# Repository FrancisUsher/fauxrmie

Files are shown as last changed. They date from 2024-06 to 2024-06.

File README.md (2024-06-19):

# fauxrmie

A derivative of the [2040rmie](https://github.com/shinkaimayano/2040rmie) drop-in PCB for the [40rmie](https://p3dstore.com/products/40rmie-invisibolt-acrylic-keyboard-case-and-pcb) family of keyboards using 40s modifiers.

The original [40s-2040rmie](https://github.com/shinkaimayano/40s-2040rmie) USB
port and rotary encoder position were slightly off. This probably didn't matter
for the acrylic or 3d printed cases, but for the 40rmie LX the tolerances seem
to have gotten a bit tighter, so I adjusted them to the correct position.

Additionally I simplified the layout options to only use the ones I am
interested in. It should be pretty straightforward to add additional e.g.
bottom-row layouts though.

## Status: Limited testing

I have tested this in my 40rmie LX using the no-blockers, no-encoders layout.

There should be no problems using the other layouts as I put quite a bit of
effort into checking the component positions matched the original PCB. However
_Order at your own risk!_

## Production

Dimensions: 309.5625mm x 112.0325mm

The files in `jlcpcb` should contain everything you need to need to order PCBA
from JLCPCB as of their January 2024 component selection.

The cost of production for 5 units was roughly $20 per unit with a 5 day turnaround:

- `$17` for PCB production (1 day)
- `$35.91` for components + PCB assembly (2 days)
- `$50` for DHL Express delivery (2 days)

## Renders

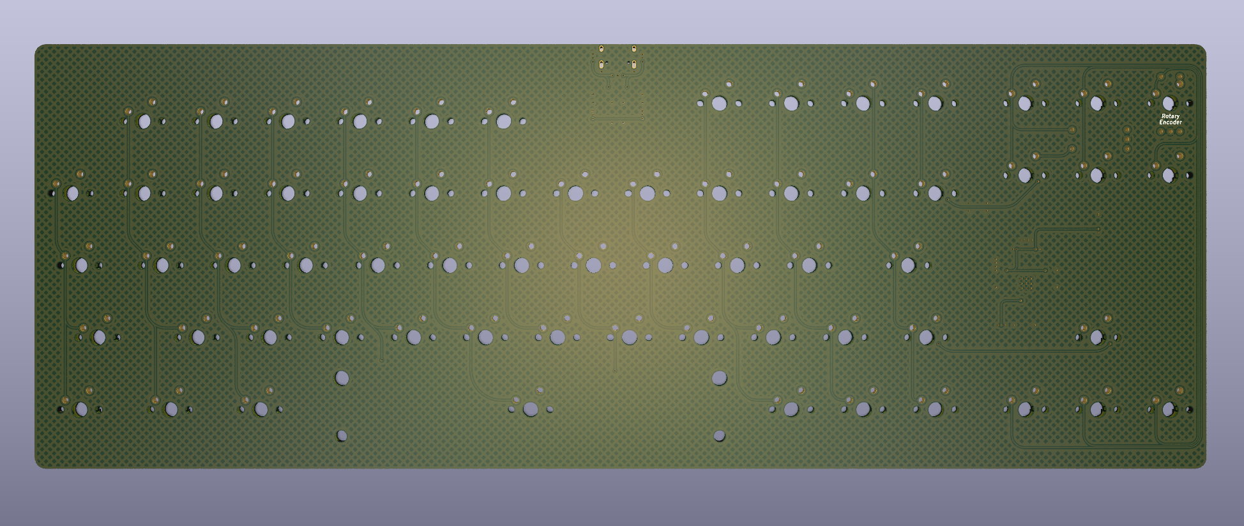
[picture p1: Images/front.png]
Front
  
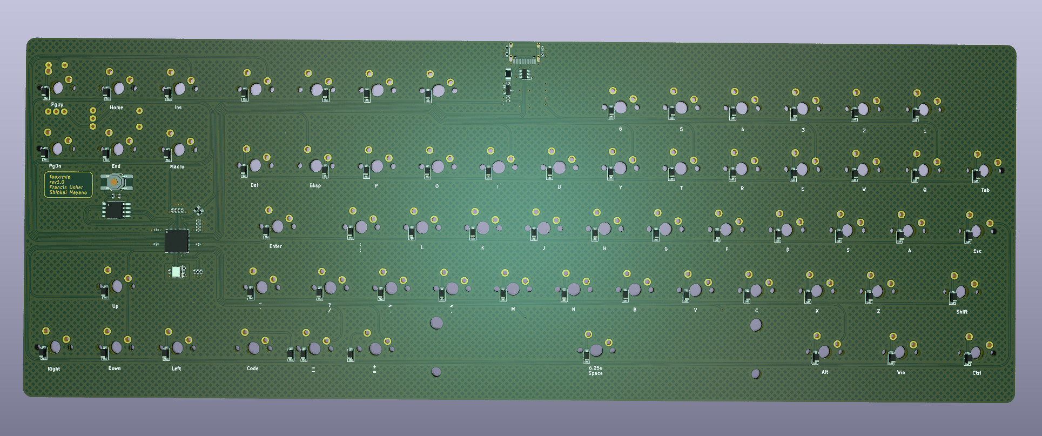
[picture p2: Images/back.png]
Back


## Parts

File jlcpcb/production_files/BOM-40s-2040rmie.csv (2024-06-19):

Comment | Designator | Footprint | LCSC
1k | R4,R8,R9 | R_0402_1005Metric | C11702
100nF | C12,C13,C14,C15,C16,C17,C18,C19,C20,C4,C8,C9 | C_0402_1005Metric | C1525
4.7nF | C3 | C_0402_1005Metric | C1538
22pF | C1,C2 | C_0402_1005Metric | C1555
HRO-M-12 | USB1 | USB_C_Receptacle_HRO_TYPE-C-31-M-12 | C165948
RP2040 | U1 | RP2040-QFN-56 | C2040
4.7uF | C10 | C_0402_1005Metric | C23733
27 | R2,R3 | R_0603_1608Metric | C25190
5.1k | R5,R6 | R_0402_1005Metric | C25905
1M | R7 | R_0402_1005Metric | C26083
Reset Button | Reset1 | SW_SPST_SKQG_WithStem | C318884
1uF | C11,C5,C6,C7 | C_0402_1005Metric | C52923
XC6206PxxxMR | U4 | SOT-23 | C5446
500mA | F1 | Fuse_1206_3216Metric | C70076
D_Small | D10,D11,D12,D13,D14,D15,D16,D17,D18,D19,D2,D20,D21,D22,D23,D24,D25,D26,D27,D28,D29,D3,D30,D31,D32,D33,D34,D35,D36,D37,D38,D39,D4,D40,D41,D42,D43,D44,D45,D46,D47,D48,D49,D5,D50,D51,D52,D53,D54,D55,D56,D57,D58,D59,D6,D63,D64,D65,D66,D67,D68,D7,D8,D9 | D_SOD-123 | C81598
SRV05-4 | U2 | SOT-23-6-routable | C85364
12MHz | Y1 | Crystal_SMD_3225-4Pin_3.2x2.5mm | C9002
W25Q128JVS | U3 | SOIC-8_5.23x5.23mm_P1.27mm | C97521

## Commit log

2023-11-17 commit work from months ago, forget what i did
    [40s-2040rmie-B_Mask.gbr, 40s-2040rmie-B_Silkscreen.gbr, 40s-2040rmie-Edge_Cuts.gbr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]
2024-06-19 add modified positions, remove extra files, update production instructions and files
    [40s-2040rmie-B_Cu.gbr, 40s-2040rmie-B_Mask.gbr, 40s-2040rmie-B_Silkscreen.gbr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]
